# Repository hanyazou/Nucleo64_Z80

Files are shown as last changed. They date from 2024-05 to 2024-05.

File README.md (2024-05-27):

# Nucleo64 Z80

Nucleo64 Z80 is a Z80 expansion board for the STM32 Nucleo 64 board.
It adds a Z80 CPU and SRAM to the Nucleo.
The Z80's I/O access is handled by the STM32 MCU on the Nucleo.

## Features

- Simple 2-chip configuration with Z80 and SRAM, no additional logic IC needed
- Board test firmware includes Microsoft BASIC
- Faster Z80 CPU execution (clock up to 20MHz)
- I2C and SPI devices can be used with the Z80 (custom firmware required)

The Nucleo64 Z80 is derived from satoshiokue's MEZ80RAM and SuperMEZ80-CPM.

## Appearance

The white boards in the following pictures are the Nucleo64 Z80.

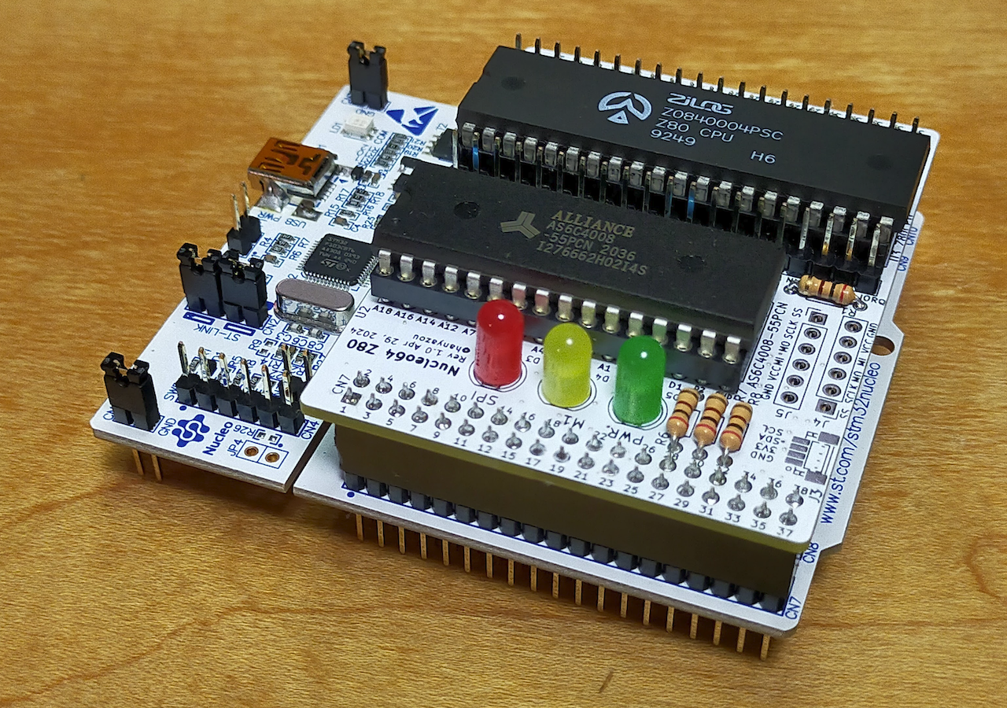
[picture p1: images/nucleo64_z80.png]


## Block Diagram

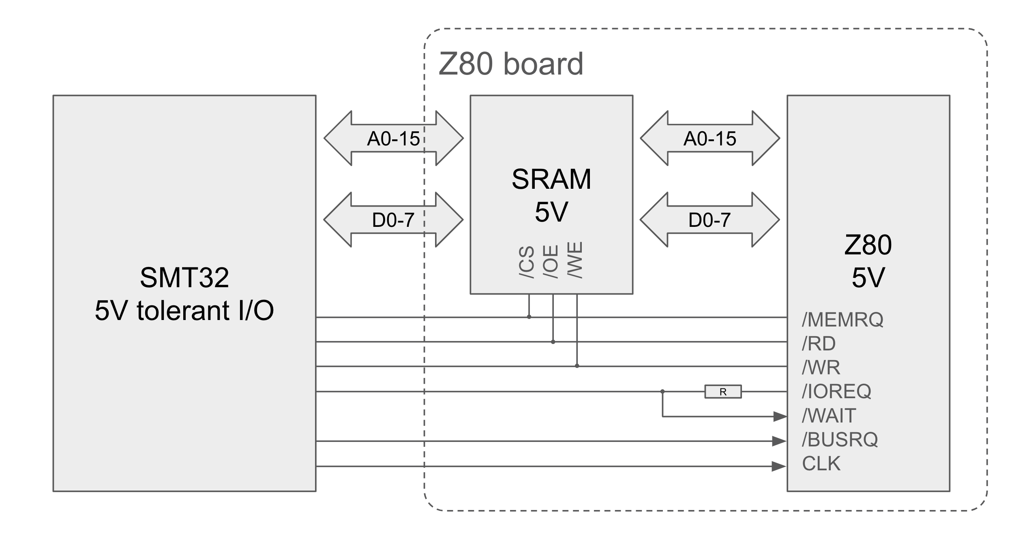
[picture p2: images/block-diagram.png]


## Required Components

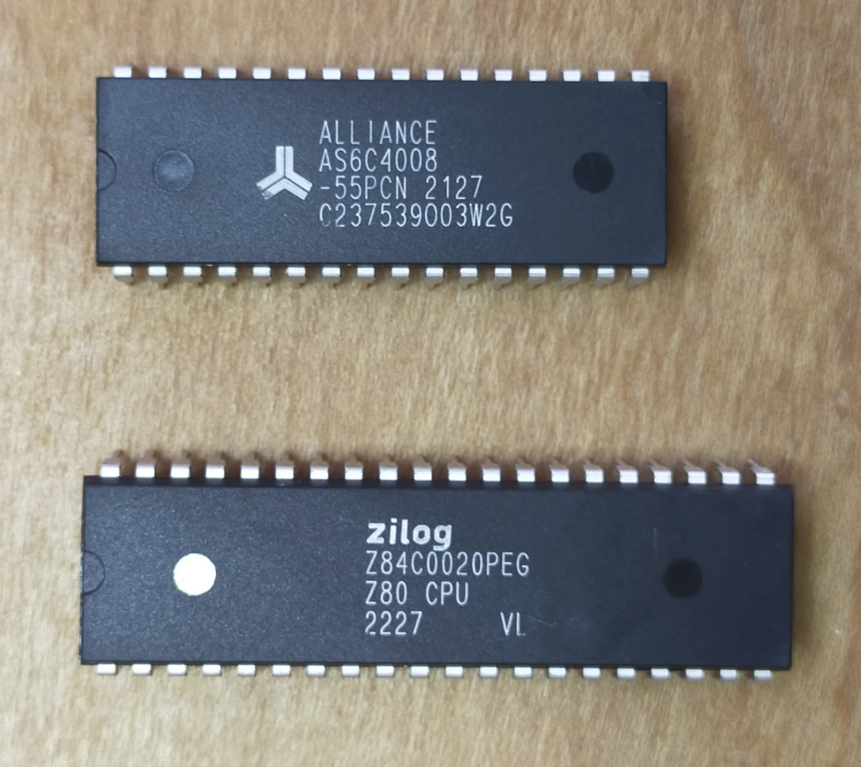
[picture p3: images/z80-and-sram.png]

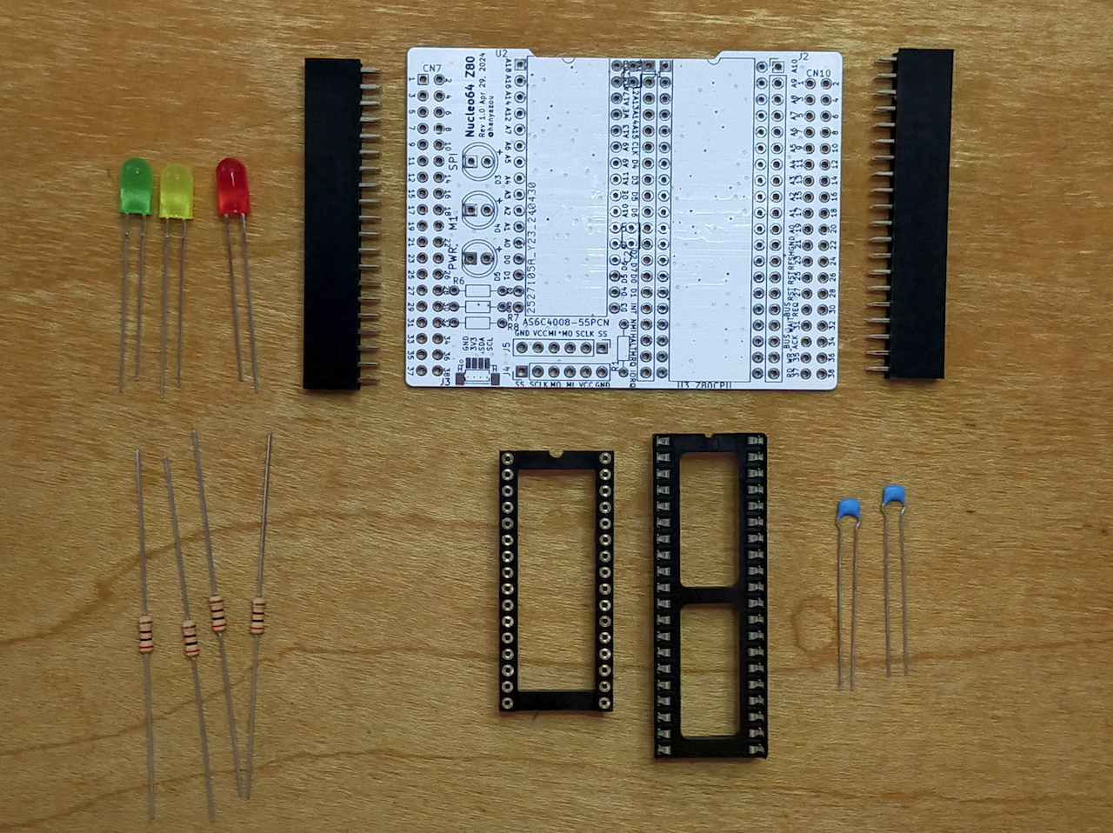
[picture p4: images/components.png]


### ICs

- U3 Z80 (DIP 40 pin) *1
- U2 AS6C4008-55 SRAM 4Mbit (DIP 32 pin) *2

### Through-hole Components

- U3 IC socket (DIP 40 pin)
- U2 IC socket (DIP 32 pin)
- C1, C2 Capacitors 0.1uF
- R1 Resistor 200 ohms
- J4, J5 Pin headers (0.1" pitch 19x2 pin)
- D3, D4, D5 LEDs
- R6, R7, R8 Resistors 100 ohms 1/4W (resistor value may vary depending on the LED)

### Optional Components

- J3 SH 1.0 JST 4 pin connector *3
- J4, J5 Pin sockets (0.1" pitch 6x1 pin) *4

*1) Z80C0004 (4MHz) or higher recommended  
*2) 512Kbit (64KB) might be sufficient  
*3) For I2C Qwiic devices  
*4) For the micro SD card slot, use the one for ARM Arduino as shown on the following page:  
https://www.amazon.com/dp/B0B7WZQVHS

## Build Instructions

With fewer components, assembly is straightforward.
Solder all components except the 19x2 pin headers first, then solder the pin headers last.

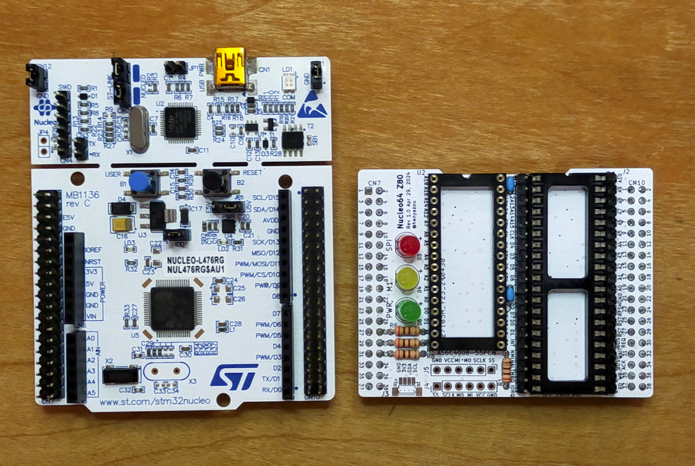
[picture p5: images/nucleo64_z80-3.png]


## Board Test Firmware

The `FW/board_test` folder contains a test firmware project for STM32 CubeIDE.
The current target is STM32 Nucleo-64 STM32L476RG.

This firmware includes Microsoft BASIC.
When the Z80 runs at 20 MHz, executing ASCIIARTM.BAS takes 61 seconds.

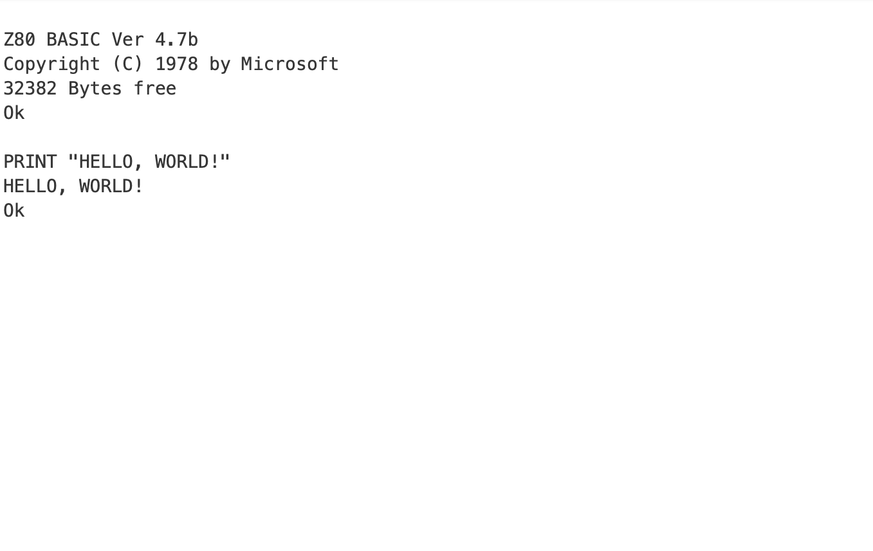
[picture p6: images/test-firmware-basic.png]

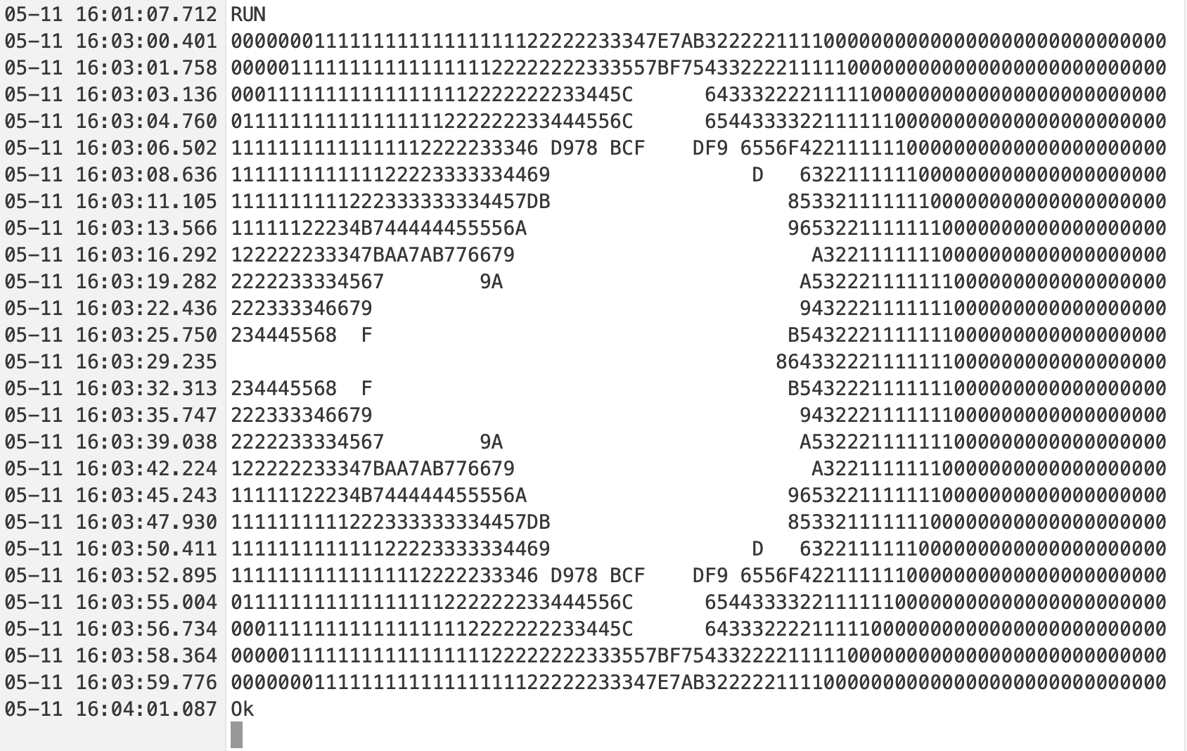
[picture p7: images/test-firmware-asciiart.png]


The Z80 clock is generated by TIM5 in the STM32 L476RG.
The prescaler of TIM5 is set to 10 - 1, so the Z80 runs at 4 MHz, which is 1/20 of the system clock (80 MHz).
If you change the prescaler to 1, the clock will be 20 MHz.

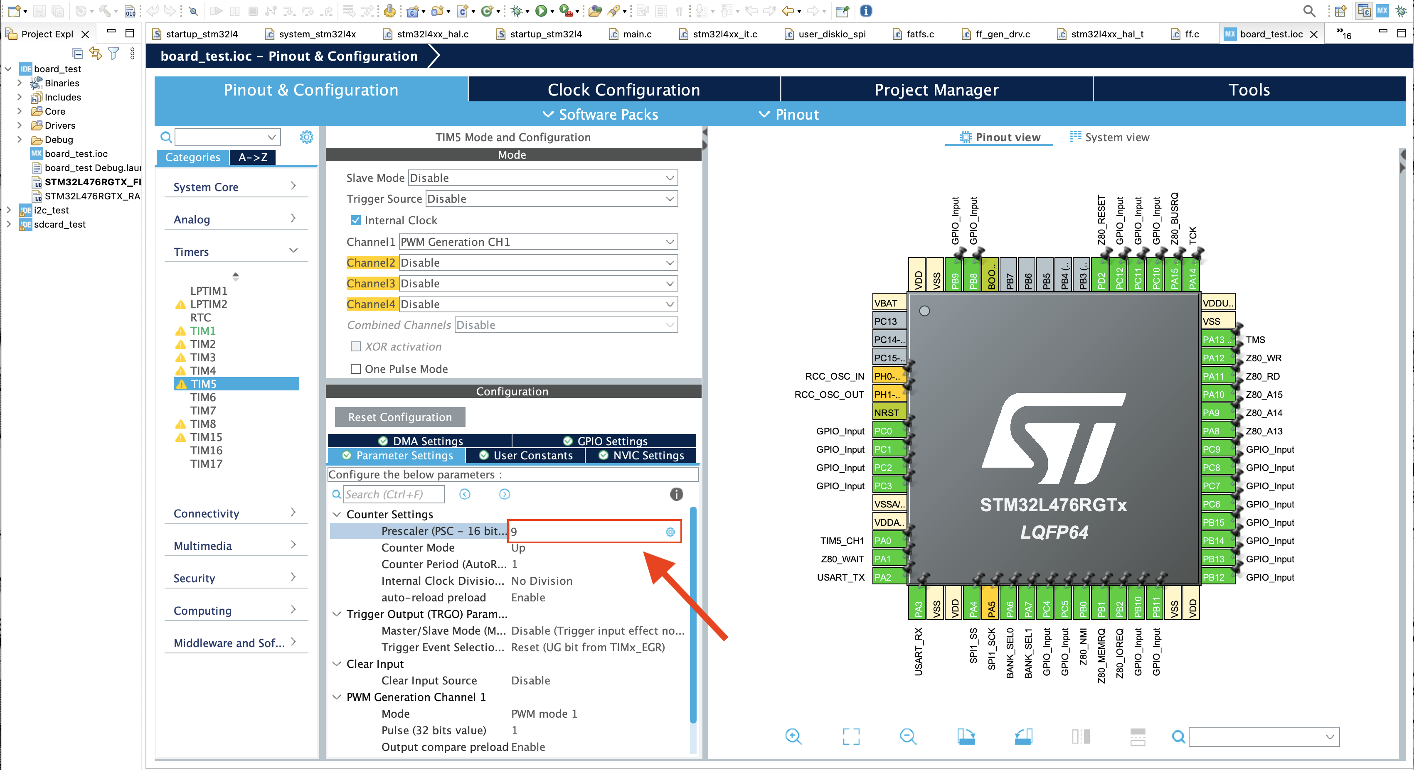
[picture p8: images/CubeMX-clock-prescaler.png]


## References

### SuperMEZ80-CPM

https://github.com/hanyazou/SuperMEZ80-CPM

### EMUZ80

https://vintagechips.wordpress.com/2022/03/05/emuz80_reference/

### MEZ80RAM

https://github.com/satoshiokue/MEZ80RAM

### NUCLEO-L476RG

https://www.st.com/en/evaluation-tools/nucleo-l476rg.html

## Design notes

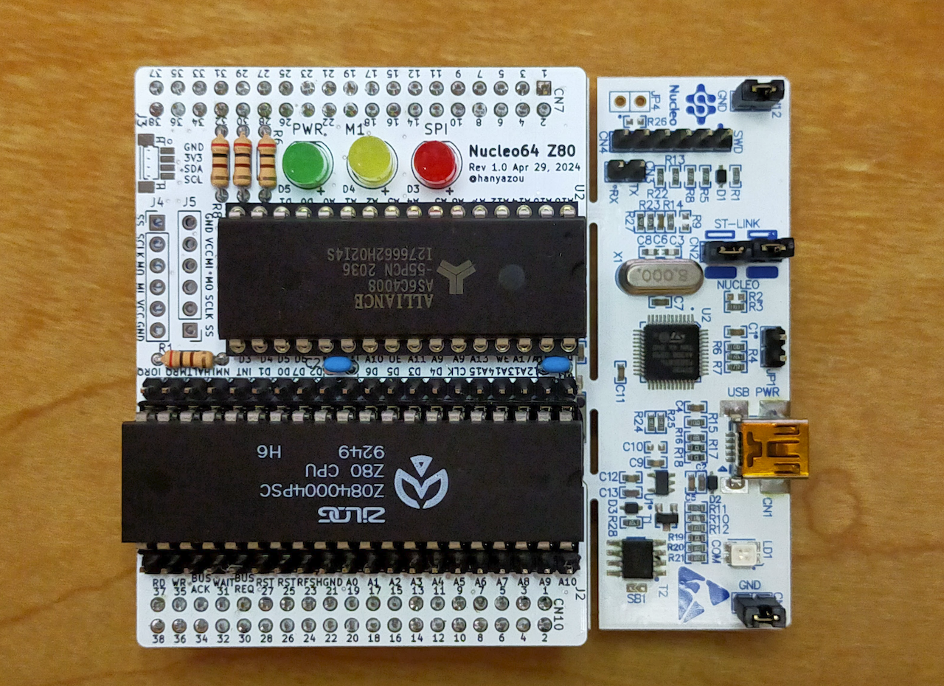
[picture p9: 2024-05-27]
images/nucleo64_z80-2.png

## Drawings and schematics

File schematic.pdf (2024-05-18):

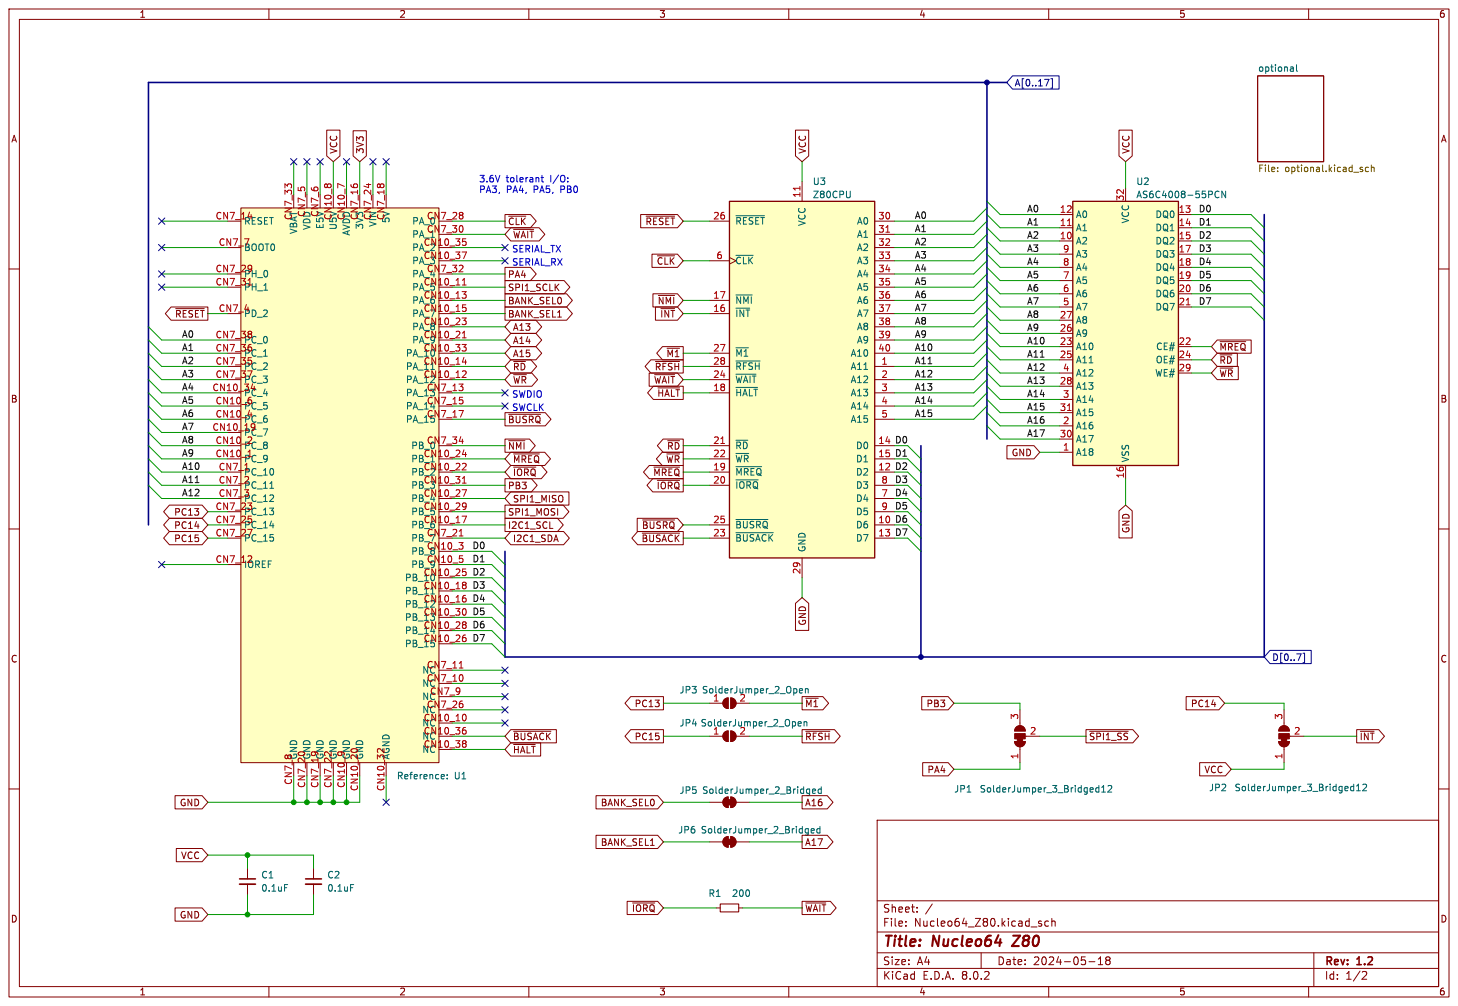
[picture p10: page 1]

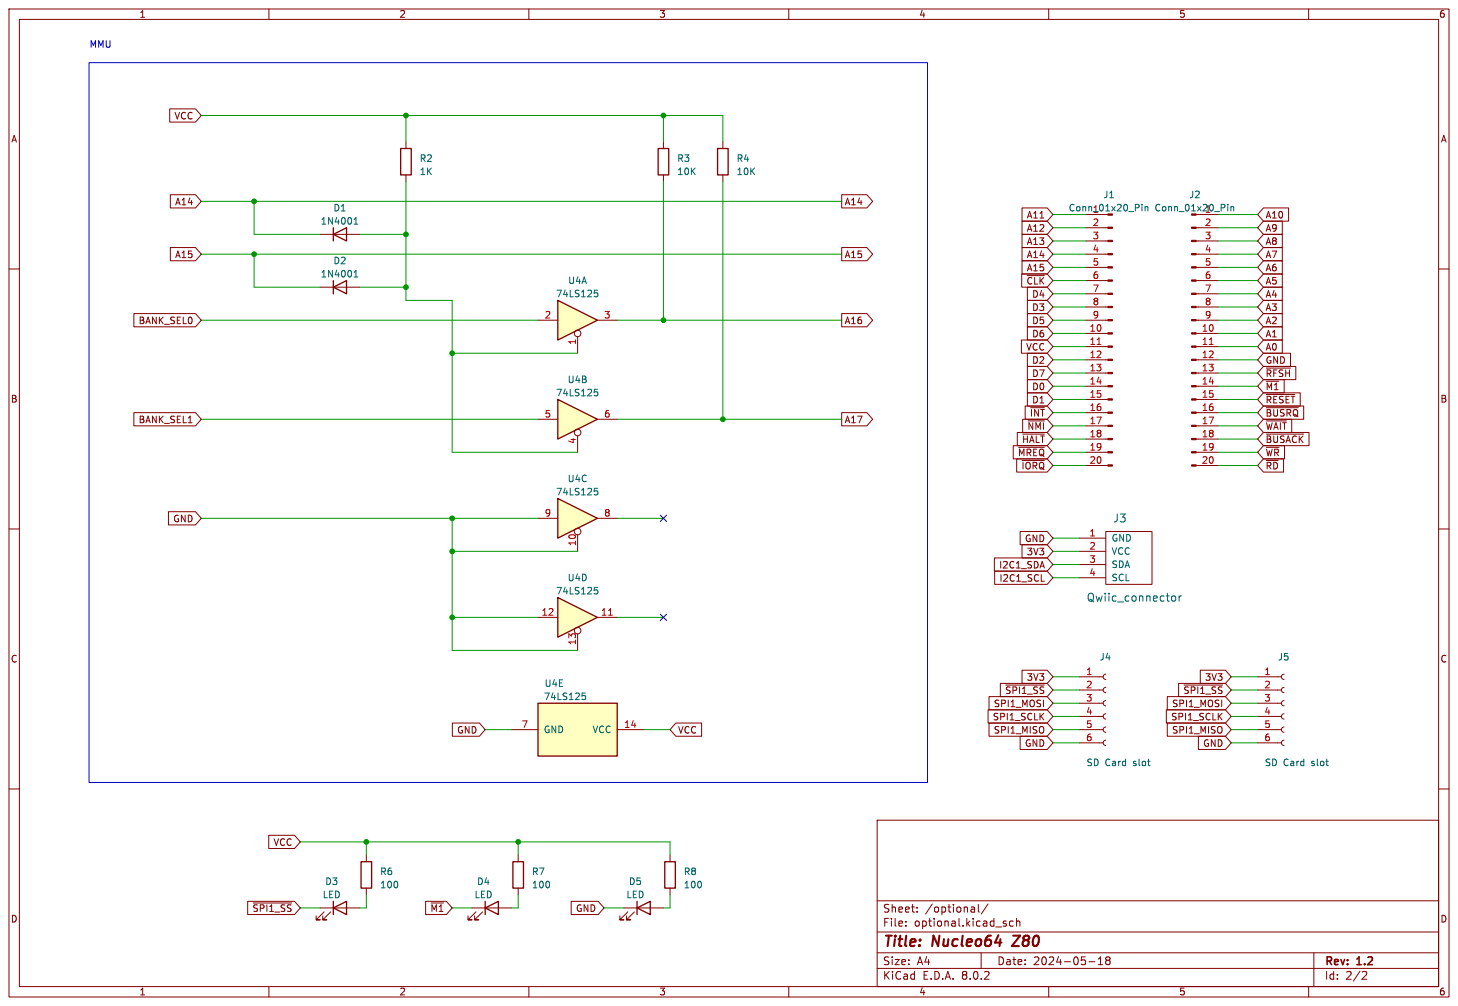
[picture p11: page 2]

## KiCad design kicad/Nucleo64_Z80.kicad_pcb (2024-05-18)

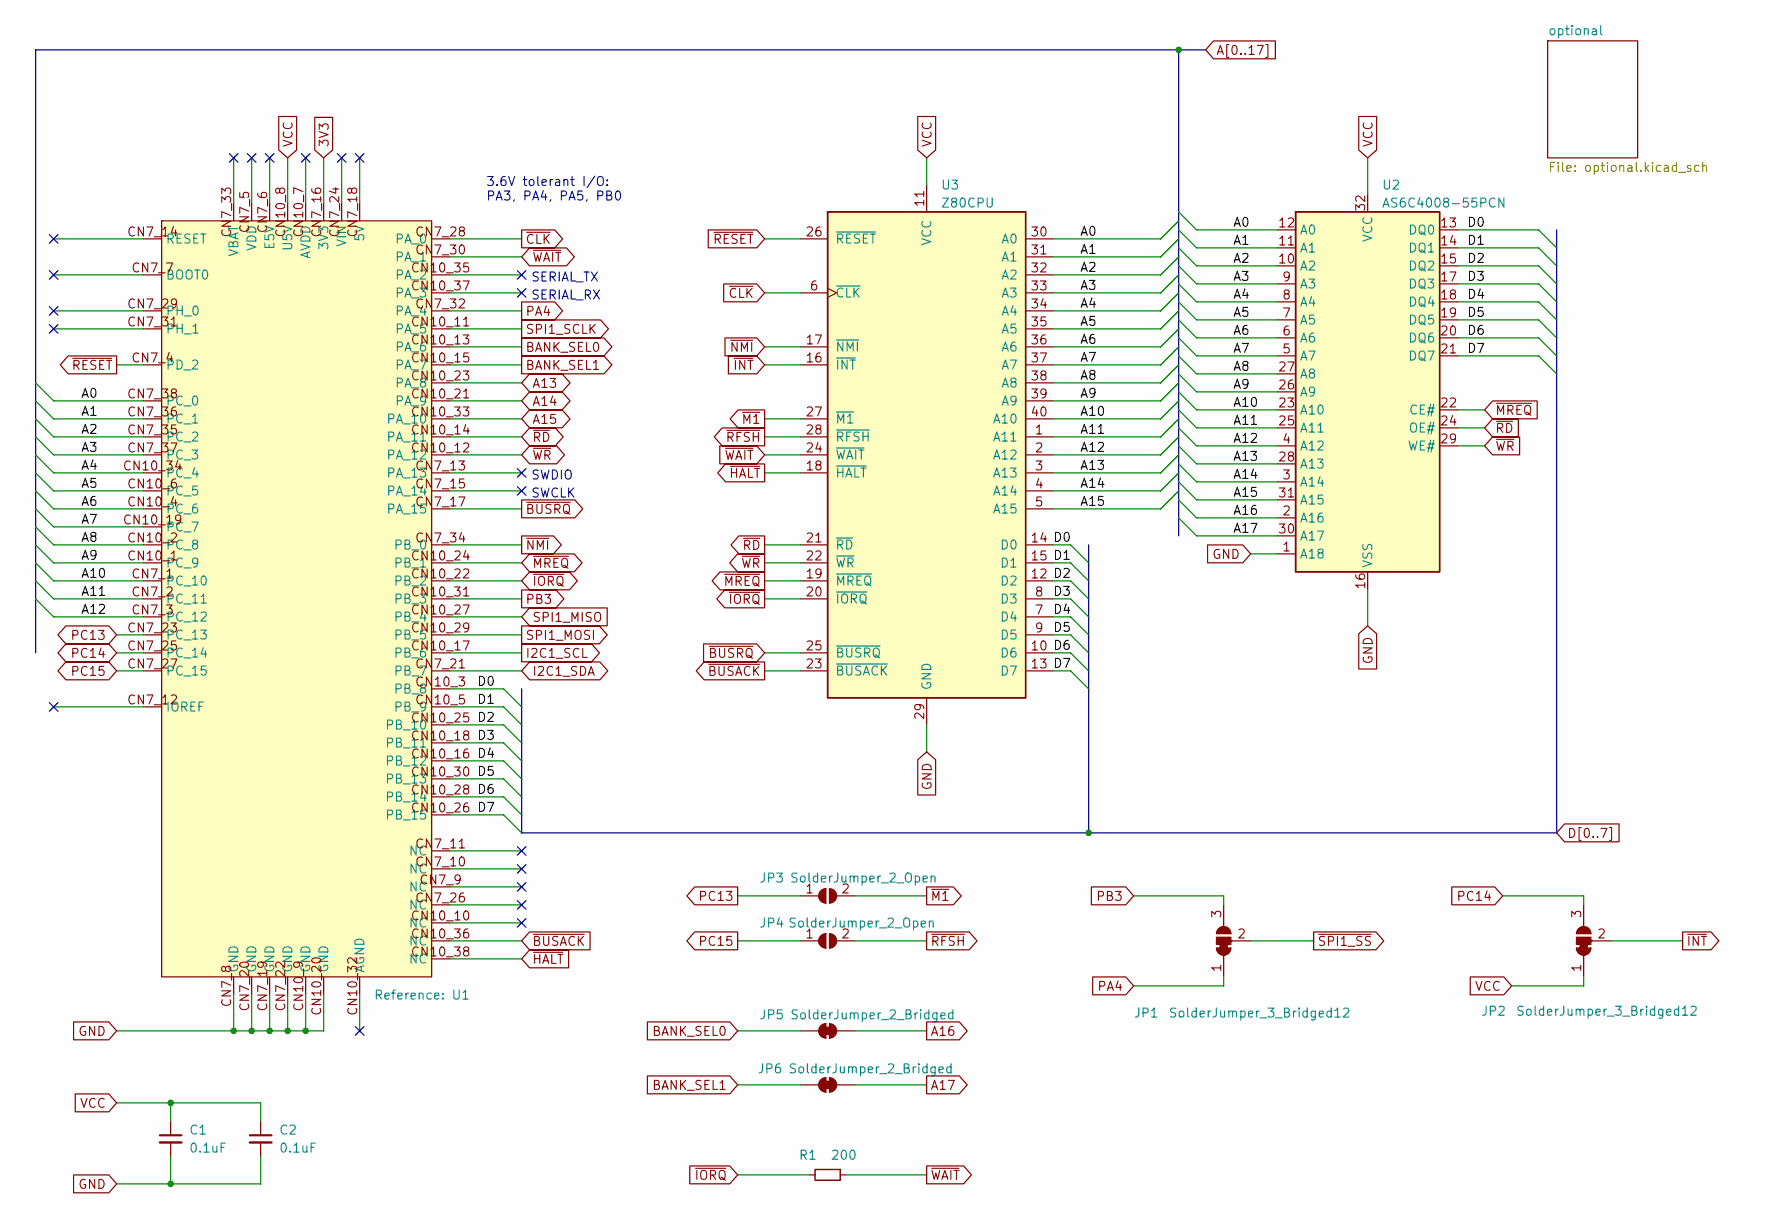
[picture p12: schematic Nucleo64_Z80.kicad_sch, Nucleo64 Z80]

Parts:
C1, C2: 0.1uF; C_Disc_D3.8mm_W2.6mm_P2.50mm
JP1, JP2: SolderJumper_3_Bridged12; SolderJumper-3_P1.3mm_Bridged12_RoundedPad1.0x1.5mm_NumberL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
JP3, JP4: SolderJumper_2_Open; SolderJumper-2_P1.3mm_Open_RoundedPad1.0x1.5mm
JP5, JP6: SolderJumper_2_Bridged; SolderJumper-2_P1.3mm_Bridged_RoundedPad1.0x1.5mm
R1: 200; R_Axial_DIN0204_L3.6mm_D1.6mm_P7.62mm_Horizontal
U1: NUCLEO64_morpho
U2: AS6C4008-55PCN; DIP-32_W15.24mm
U3: Z80CPU; DIP-40_W15.24mm

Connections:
3V3: U1.CN7_16 (3V3); also elsewhere on the board
A0: U1.CN7_38 (PC_0), U2.12 (A0), U3.30 (A0); also elsewhere on the board
A1: U1.CN7_36 (PC_1), U2.11 (A1), U3.31 (A1); also elsewhere on the board
A2: U1.CN7_35 (PC_2), U2.10 (A2), U3.32 (A2); also elsewhere on the board
A3: U1.CN7_37 (PC_3), U2.9 (A3), U3.33 (A3); also elsewhere on the board
A4: U1.CN10_34 (PC_4), U2.8 (A4), U3.34 (A4); also elsewhere on the board
A5: U1.CN10_6 (PC_5), U2.7 (A5), U3.35 (A5); also elsewhere on the board
A6: U1.CN10_4 (PC_6), U2.6 (A6), U3.36 (A6); also elsewhere on the board
A7: U1.CN10_19 (PC_7), U2.5 (A7), U3.37 (A7); also elsewhere on the board
A8: U1.CN10_2 (PC_8), U2.27 (A8), U3.38 (A8); also elsewhere on the board
A9: U1.CN10_1 (PC_9), U2.26 (A9), U3.39 (A9); also elsewhere on the board
A10: U1.CN7_1 (PC_10), U2.23 (A10), U3.40 (A10); also elsewhere on the board
A11: U1.CN7_2 (PC_11), U2.25 (A11), U3.1 (A11); also elsewhere on the board
A12: U1.CN7_3 (PC_12), U2.4 (A12), U3.2 (A12); also elsewhere on the board
A13: U1.CN10_23 (PA_8), U2.28 (A13), U3.3 (A13); also elsewhere on the board
A14: U1.CN10_21 (PA_9), U2.3 (A14), U3.4 (A14); also elsewhere on the board
A15: U1.CN10_33 (PA_10), U2.31 (A15), U3.5 (A15); also elsewhere on the board
A16: JP5.2 (B), U2.2 (A16); also elsewhere on the board
A17: JP6.2 (B), U2.30 (A17); also elsewhere on the board
BANK_SEL0: JP5.1 (A), U1.CN10_13 (PA_6); also elsewhere on the board
BANK_SEL1: JP6.1 (A), U1.CN10_15 (PA_7); also elsewhere on the board
D0: U1.CN10_3 (PB_8), U2.13 (DQ0), U3.14 (D0); also elsewhere on the board
D1: U1.CN10_5 (PB_9), U2.14 (DQ1), U3.15 (D1); also elsewhere on the board
D2: U1.CN10_25 (PB_10), U2.15 (DQ2), U3.12 (D2); also elsewhere on the board
D3: U1.CN10_18 (PB_11), U2.17 (DQ3), U3.8 (D3); also elsewhere on the board
D4: U1.CN10_16 (PB_12), U2.18 (DQ4), U3.7 (D4); also elsewhere on the board
D5: U1.CN10_30 (PB_13), U2.19 (DQ5), U3.9 (D5); also elsewhere on the board
D6: U1.CN10_28 (PB_14), U2.20 (DQ6), U3.10 (D6); also elsewhere on the board
D7: U1.CN10_26 (PB_15), U2.21 (DQ7), U3.13 (D7); also elsewhere on the board
GND: C1.2, C2.2, U1.CN7_8 (GND), U1.CN7_19 (GND), U1.CN7_20 (GND), U1.CN7_22 (GND), U1.CN10_9 (GND), U1.CN10_20 (GND), U2.1 (A18), U2.16 (VSS), U3.29 (GND); also elsewhere on the board
I2C1_SCL: U1.CN10_17 (PB_6); also elsewhere on the board
I2C1_SDA: U1.CN7_21 (PB_7); also elsewhere on the board
PA4: JP1.1 (A), U1.CN7_32 (PA_4)
PB3: JP1.3 (B), U1.CN10_31 (PB_3)
PC13: JP3.1 (A), U1.CN7_23 (PC_13)
PC14: JP2.3 (B), U1.CN7_25 (PC_14)
PC15: JP4.1 (A), U1.CN7_27 (PC_15)
SPI1_MISO: U1.CN10_27 (PB_4); also elsewhere on the board
SPI1_MOSI: U1.CN10_29 (PB_5); also elsewhere on the board
SPI1_SCLK: U1.CN10_11 (PA_5); also elsewhere on the board
VCC: C1.1, C2.1, JP2.1 (A), U1.CN10_8 (U5V), U2.32 (VCC), U3.11 (VCC); also elsewhere on the board
~BUSACK: U1.CN10_36 (NC), U3.23 (~BUSACK); also elsewhere on the board
~BUSRQ: U1.CN7_17 (PA_15), U3.25 (~BUSRQ); also elsewhere on the board
~CLK: U1.CN7_28 (PA_0), U3.6 (~CLK); also elsewhere on the board
~HALT: U1.CN10_38 (NC), U3.18 (~HALT); also elsewhere on the board
~INT: JP2.2 (C), U3.16 (~INT); also elsewhere on the board
~IORQ: R1.2, U1.CN10_22 (PB_2), U3.20 (~IORQ); also elsewhere on the board
~M1: JP3.2 (B), U3.27 (~M1); also elsewhere on the board
~MREQ: U1.CN10_24 (PB_1), U2.22 (CE#), U3.19 (~MREQ); also elsewhere on the board
~NMI: U1.CN7_34 (PB_0), U3.17 (~NMI); also elsewhere on the board
~RD: U1.CN10_14 (PA_11), U2.24 (OE#), U3.21 (~RD); also elsewhere on the board
~RESET: U1.CN7_4 (PD_2), U3.26 (~RESET); also elsewhere on the board
~RFSH: JP4.2 (B), U3.28 (~RFSH); also elsewhere on the board
~SPI1_SS: JP1.2 (C); also elsewhere on the board
~WAIT: R1.1, U1.CN7_30 (PA_1), U3.24 (~WAIT); also elsewhere on the board
~WR: U1.CN10_12 (PA_12), U2.29 (WE#), U3.22 (~WR); also elsewhere on the board

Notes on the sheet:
SWDIO
SERIAL_RX
SERIAL_TX
SWCLK
3.6V tolerant I/O: PA3, PA4, PA5, PB0

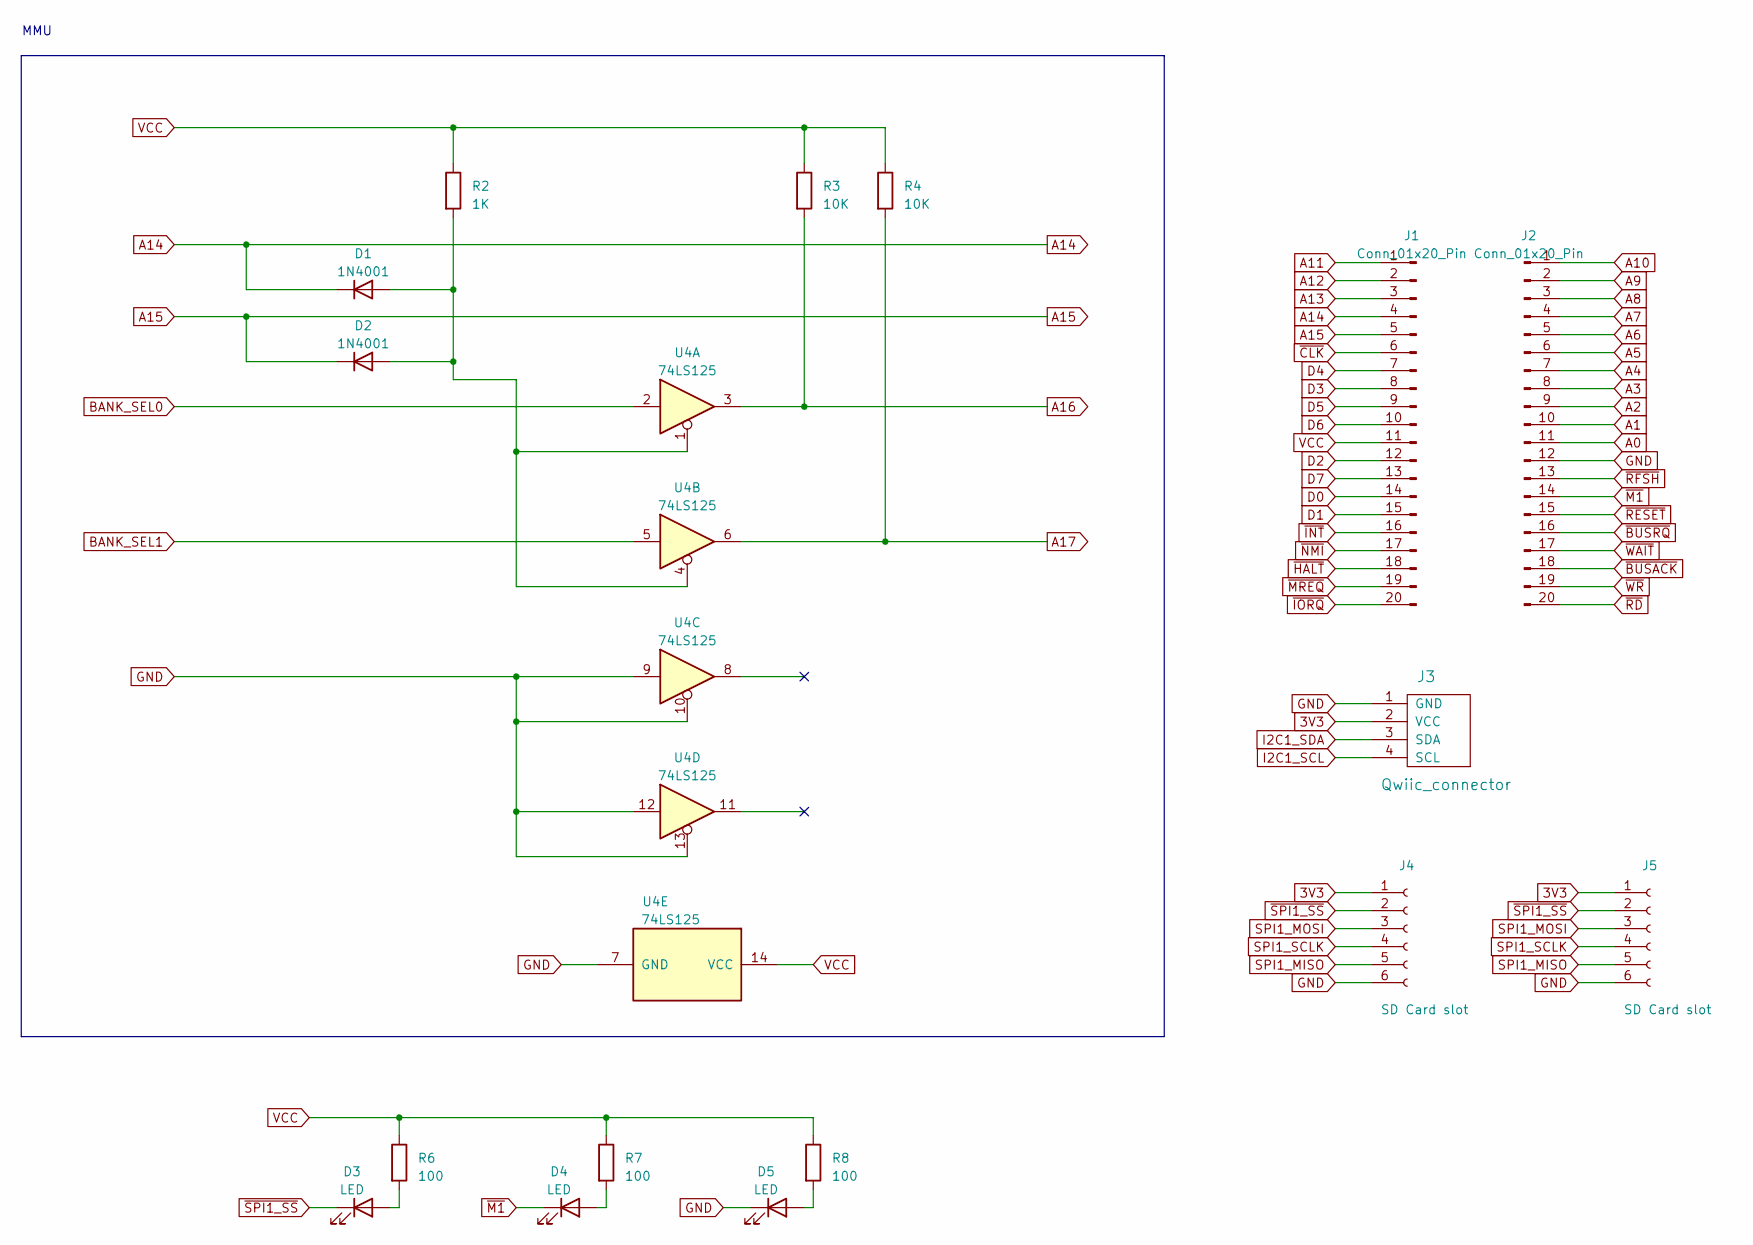
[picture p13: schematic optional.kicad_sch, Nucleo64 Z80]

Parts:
D1, D2: 1N4001; D_0805_2012Metric_Pad1.15x1.40mm_HandSolder
D3, D4, D5: LED; LED_D5.0mm
J1, J2: Conn_01x20_Pin; PinHeader_1x20_P2.54mm_Vertical
J3: Qwiic_connector; Qwiic_I2C_1.00mm_4pin
J4, J5: SD Card slot; PinHeader_1x06_P2.54mm_Vertical
R2: 1K; R_0805_2012Metric_Pad1.20x1.40mm_HandSolder
R3, R4: 10K; R_0805_2012Metric_Pad1.20x1.40mm_HandSolder
R6, R7, R8: 100; R_Axial_DIN0204_L3.6mm_D1.6mm_P7.62mm_Horizontal
U4: 74LS125; SSOP-14_5.3x6.2mm_P0.65mm

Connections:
3V3: J3.2 (VCC), J4.1, J5.1; also elsewhere on the board
A0: J2.11; also elsewhere on the board
A1: J2.10; also elsewhere on the board
A2: J2.9; also elsewhere on the board
A3: J2.8; also elsewhere on the board
A4: J2.7; also elsewhere on the board
A5: J2.6; also elsewhere on the board
A6: J2.5; also elsewhere on the board
A7: J2.4; also elsewhere on the board
A8: J2.3; also elsewhere on the board
A9: J2.2; also elsewhere on the board
A10: J2.1; also elsewhere on the board
A11: J1.1; also elsewhere on the board
A12: J1.2; also elsewhere on the board
A13: J1.3; also elsewhere on the board
A14: D1.1 (K), J1.4; also elsewhere on the board
A15: D2.1 (K), J1.5; also elsewhere on the board
A16: R3.2, U4.3; also elsewhere on the board
A17: R4.2, U4.6; also elsewhere on the board
BANK_SEL0: U4.2; also elsewhere on the board
BANK_SEL1: U4.5; also elsewhere on the board
D0: J1.14; also elsewhere on the board
D1: J1.15; also elsewhere on the board
D2: J1.12; also elsewhere on the board
D3: J1.8; also elsewhere on the board
D4: J1.7; also elsewhere on the board
D5: J1.9; also elsewhere on the board
D6: J1.10; also elsewhere on the board
D7: J1.13; also elsewhere on the board
GND: D5.1 (K), J2.12, J3.1 (GND), J4.6, J5.6, U4.7 (GND), U4.9, U4.10, U4.12, U4.13; also elsewhere on the board
I2C1_SCL: J3.4 (SCL); also elsewhere on the board
I2C1_SDA: J3.3 (SDA); also elsewhere on the board
unnamed: D1.2 (A), D2.2 (A), R2.2, U4.1, U4.4
unnamed: D3.2 (A), R6.2
unnamed: D4.2 (A), R7.2
unnamed: D5.2 (A), R8.2
SPI1_MISO: J4.5, J5.5; also elsewhere on the board
SPI1_MOSI: J4.3, J5.3; also elsewhere on the board
SPI1_SCLK: J4.4, J5.4; also elsewhere on the board
VCC: J1.11, R2.1, R3.1, R4.1, R6.1, R7.1, R8.1, U4.14 (VCC); also elsewhere on the board
~BUSACK: J2.18; also elsewhere on the board
~BUSRQ: J2.16; also elsewhere on the board
~CLK: J1.6; also elsewhere on the board
~HALT: J1.18; also elsewhere on the board
~INT: J1.16; also elsewhere on the board
~IORQ: J1.20; also elsewhere on the board
~M1: D4.1 (K), J2.14; also elsewhere on the board
~MREQ: J1.19; also elsewhere on the board
~NMI: J1.17; also elsewhere on the board
~RD: J2.20; also elsewhere on the board
~RESET: J2.15; also elsewhere on the board
~RFSH: J2.13; also elsewhere on the board
~SPI1_SS: D3.1 (K), J4.2, J5.2; also elsewhere on the board
~WAIT: J2.17; also elsewhere on the board
~WR: J2.19; also elsewhere on the board

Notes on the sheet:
MMU

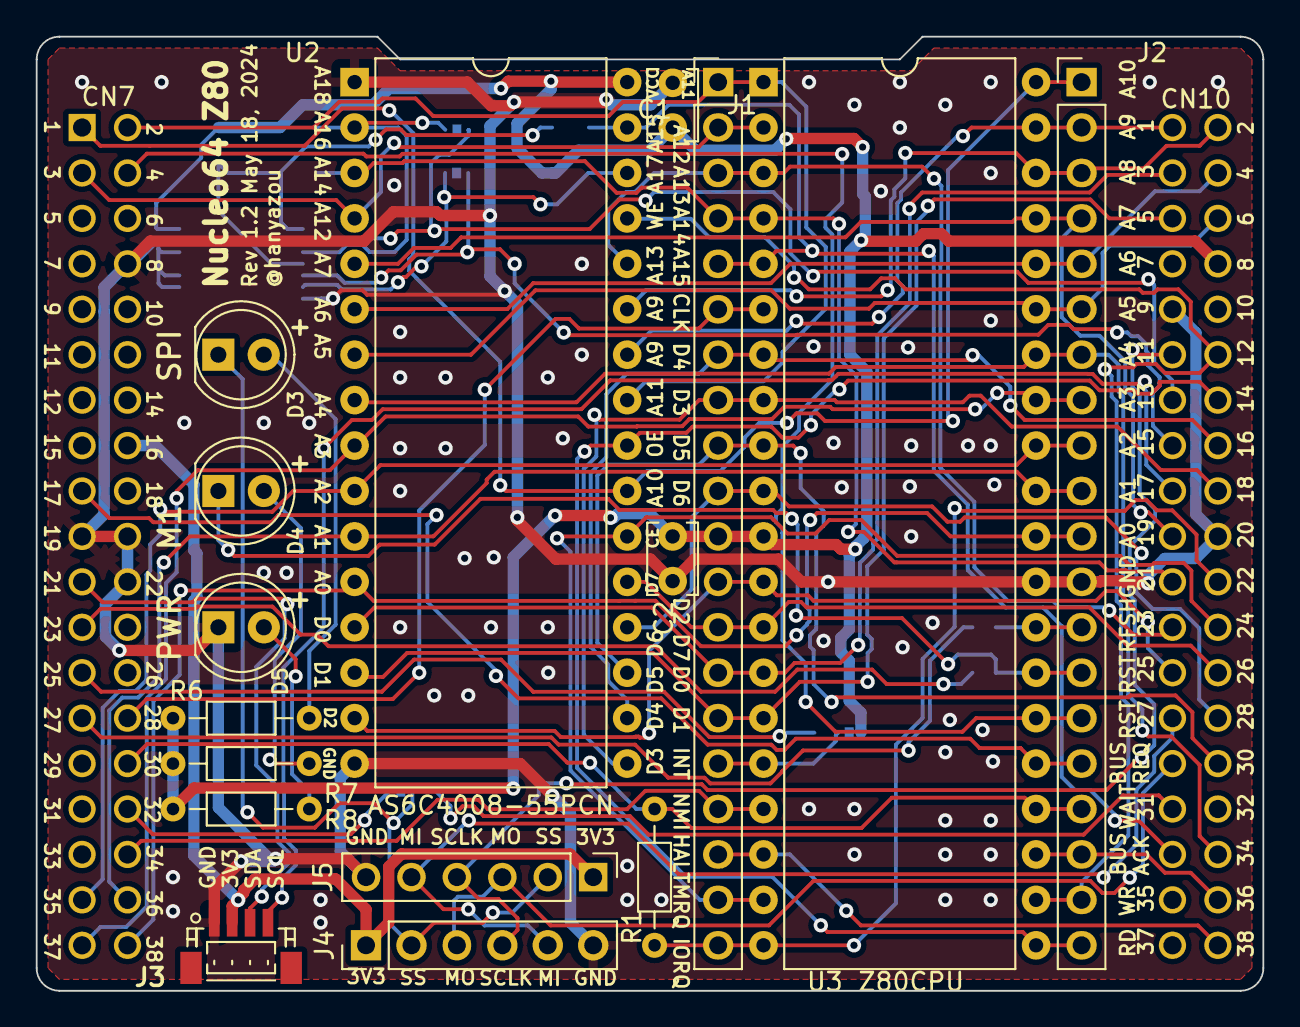
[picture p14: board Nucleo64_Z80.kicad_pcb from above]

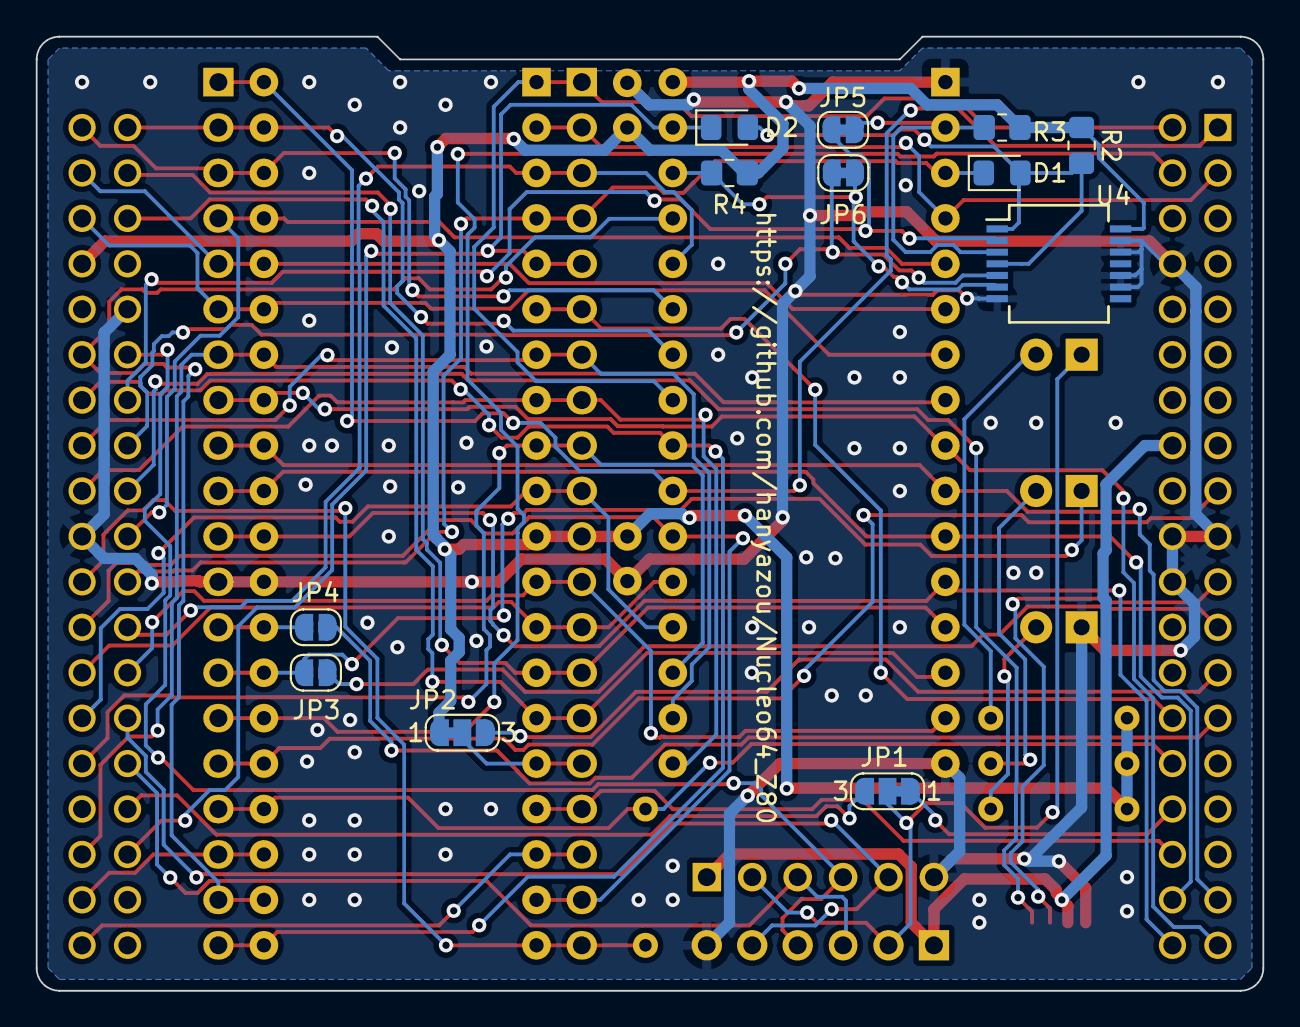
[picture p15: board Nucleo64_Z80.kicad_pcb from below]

Board: 2 copper layers, 68.6 x 53.3 mm, 29 parts (12 on the bottom side), 60 nets.

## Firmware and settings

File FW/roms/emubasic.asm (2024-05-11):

;	EMUBASIC based on GRANT's BASIC
;	TARGET: EMUZ80
;	ASSEMBLER: ARCPIT XZ80.EXE
;
;	START UP ROUTINE
;	VERSION 1.0, 2022/02/15
;	WRITTEN by TETSUYA SUZUKI
;
;	MEMORY ASIGN
ROMTOP	EQU	0000H
RAMTOP	EQU	8000H
RAMSIZ	EQU	1000H
TSTACK	EQU	80EDH
;
;	UART REGISTER ADDRESS
UARTDR	EQU	00H	; UART DATA REGISTOR
UARTCR	EQU	01H	; UART CONTROL REGISTOR
;
;	RESET (RST 00H)
	ORG	ROMTOP
	DI
	LD	SP,TSTACK
	JP	SINIT
;
;	PUT 1CHAR (RST 08H)
	ORG	ROMTOP+08H
	JP	TXA
;
;	GET 1CHAR (RST 10H)
	ORG	ROMTOP+10H
	JP	RXA
;
;	KBHIT (RST 18H)
	ORG	ROMTOP+18H
	JP	KBHIT
;
;	UART -> A
RXA:	IN	A,(UARTCR)
	BIT	0,A
	JR	Z,RXA
	IN	A,(UARTDR)
	CP	'a'
	RET	C
	CP	'z'+1
	RET	NC
	AND	0DFH
	RET
;
;	CHECK RECEIVE STATUS
KBHIT:	IN	A,(UARTCR)
	BIT	0,A
	RET
;
;	A -> UART
TXA:	PUSH	AF
TXAST1:	IN	A,(UARTCR)
	BIT	1,A
	JR	Z,TXAST1
	POP	AF
	OUT	(UARTDR),A
	RET
;
;
;	SYSTEM INITIALIZE
SINIT:
	JP	COLD
;
;==================================================================================
; The updates to the original BASIC within this file are copyright Grant Searle
;
; You have permission to use this for NON COMMERCIAL USE ONLY
; If you wish to use it elsewhere, please include an acknowledgement to myself.
;
; http://searle.hostei.com/grant/index.html
;
; eMail: home.micros01@btinternet.com
;
; If the above don't work, please perform an Internet search to see if I have
; updated the web page hosting service.
;
;==================================================================================
;
; NASCOM ROM BASIC Ver 4.7, (C) 1978 Microsoft
; Scanned from source published in 80-BUS NEWS from Vol 2, Issue 3
; (May-June 1983) to Vol 3, Issue 3 (May-June 1984)
; Adapted for the freeware Zilog Macro Assembler 2.10 to produce
; the original ROM code (checksum A934H). PA
;
; GENERAL EQUATES
;
CTRLC	EQU	03H		; Control "C"
CTRLG	EQU	07H		; Control "G"
BKSP	EQU	08H		; Back space
LF	EQU	0AH		; Line feed
CS	EQU	0CH		; Clear screen
CR	EQU	0DH		; Carriage return
CTRLO	EQU	0FH		; Control "O"
CTRLQ	EQU	11H		; Control "Q"
CTRLR	EQU	12H		; Control "R"
CTRLS	EQU	13H		; Control "S"
CTRLU	EQU	15H		; Control "U"
ESC	EQU	1BH		; Escape
DEL	EQU	7FH		; Delete
;
; BASIC WORK SPACE LOCATIONS
;
WRKSPC	EQU	8045H		; BASIC Work space
USR	EQU	WRKSPC+3H	; "USR (x)" jump
OUTSUB	EQU	WRKSPC+6H	; "OUT p,n"
OTPORT	EQU	WRKSPC+7H	; Port (p)
DIVSUP	EQU	WRKSPC+9H	; Division support routine
DIV1	EQU	WRKSPC+0AH	; <- Values
DIV2	EQU	WRKSPC+0EH	; <- to
DIV3	EQU	WRKSPC+12H	; <- be
DIV4	EQU	WRKSPC+15H	; <- inserted
SEED	EQU	WRKSPC+17H	; Random number seed
LSTRND	EQU	WRKSPC+3AH	; Last random number
INPSUB	EQU	WRKSPC+3EH	; #INP (x)" Routine
INPORT	EQU	WRKSPC+3FH	; PORT (x)
NULLS	EQU	WRKSPC+41H	; Number of nulls
LWIDTH	EQU	WRKSPC+42H	; Terminal width
COMMAN	EQU	WRKSPC+43H	; Width for commas
NULFLG	EQU	WRKSPC+44H	; Null after input byte flag
CTLOFG	EQU	WRKSPC+45H	; Control "O" flag
LINESC	EQU	WRKSPC+46H	; Lines counter
LINESN	EQU	WRKSPC+48H	; Lines number
CHKSUM	EQU	WRKSPC+4AH	; Array load/save check sum
NMIFLG	EQU	WRKSPC+4CH	; Flag for NMI break routine
BRKFLG	EQU	WRKSPC+4DH	; Break flag
RINPUT	EQU	WRKSPC+4EH	; Input reflection
POINT	EQU	WRKSPC+51H	; "POINT" reflection (unused)
PSET	EQU	WRKSPC+54H	; "SET"	reflection
RESET	EQU	WRKSPC+57H	; "RESET" reflection
STRSPC	EQU	WRKSPC+5AH	; Bottom of string space
LINEAT	EQU	WRKSPC+5CH	; Current line number
BASTXT	EQU	WRKSPC+5EH	; Pointer to start of program
BUFFER	EQU	WRKSPC+61H	; Input buffer
STACK	EQU	WRKSPC+66H	; Initial stack
CURPOS	EQU	WRKSPC+0ABH	; Character position on line
LCRFLG	EQU	WRKSPC+0ACH	; Locate/Create flag
TYPE	EQU	WRKSPC+0ADH	; Data type flag
DATFLG	EQU	WRKSPC+0AEH	; Literal statement flag
LSTRAM	EQU	WRKSPC+0AFH	; Last available RAM
TMSTPT	EQU	WRKSPC+0B1H	; Temporary string pointer
TMSTPL	EQU	WRKSPC+0B3H	; Temporary string pool
TMPSTR	EQU	WRKSPC+0BFH	; Temporary string
STRBOT	EQU	WRKSPC+0C3H	; Bottom of string space
CUROPR	EQU	WRKSPC+0C5H	; Current operator in EVAL
LOOPST	EQU	WRKSPC+0C7H	; First statement of loop
DATLIN	EQU	WRKSPC+0C9H	; Line of current DATA item
FORFLG	EQU	WRKSPC+0CBH	; "FOR" loop flag
LSTBIN	EQU	WRKSPC+0CCH	; Last byte entered
READFG	EQU	WRKSPC+0CDH	; Read/Input flag
BRKLIN	EQU	WRKSPC+0CEH	; Line of break
NXTOPR	EQU	WRKSPC+0D0H	; Next operator in EVAL
ERRLIN	EQU	WRKSPC+0D2H	; Line of error
CONTAD	EQU	WRKSPC+0D4H	; Where to CONTinue
PROGND	EQU	WRKSPC+0D6H	; End of program
VAREND	EQU	WRKSPC+0D8H	; End of variables
ARREND	EQU	WRKSPC+0DAH	; End of arrays
NXTDAT	EQU	WRKSPC+0DCH	; Next data item
FNRGNM	EQU	WRKSPC+0DEH	; Name of FN argument
FNARG	EQU	WRKSPC+0E0H	; FN argument value
FPREG	EQU	WRKSPC+0E4H	; Floating point register
FPEXP	EQU	FPREG+3		; Floating point exponent
SGNRES	EQU	WRKSPC+0E8H	; Sign of result
PBUFF	EQU	WRKSPC+0E9H	; Number print buffer
MULVAL	EQU	WRKSPC+0F6H	; Multiplier
PROGST	EQU	WRKSPC+0F9H	; Start of program text area
STLOOK	EQU	WRKSPC+15DH	; Start of memory test
;
; BASIC ERROR CODE VALUES
;
NF	EQU	00H		; NEXT without FOR
SN	EQU	02H		; Syntax error
RG	EQU	04H		; RETURN without GOSUB
OD	EQU	06H		; Out of DATA
FC	EQU	08H		; Function call error
OV	EQU	0AH		; Overflow
OM	EQU	0CH		; Out of memory
UL	EQU	0EH		; Undefined line number
BS	EQU	10H		; Bad subscript
RD	EQU	12H		; Re-DIMensioned array
DZ	EQU	14H		; Division by zero (/0)
ID	EQU	16H		; Illegal direct
TM	EQU	18H		; Type miss-match
OS	EQU	1AH		; Out of string space
LS	EQU	1CH		; String too long
ST	EQU	1EH		; String formula too complex
CN	EQU	20H		; Can't CONTinue
UF	EQU	22H		; UnDEFined FN function
MO	EQU	24H		; Missing operand
HX	EQU	26H		; HEX error
BN	EQU	28H		; BIN error
;
COLD:	JP	STARTB		; Jump for cold start
WARM:	JP	WARMST		; Jump for warm start
STARTB: JP	CSTART		; Jump to initialise
;
	DW	DEINT		; Get integer -32768 to 32767
	DW	ABPASS		; Return integer in AB
;
CSTART: LD	HL,WRKSPC	; Start of workspace RAM
	LD	SP,HL		; Set up a temporary stack
	JP	INITST		; Go to initialise
;
INIT:	LD	DE,INITAB	; Initialise workspace
	LD	B,INITBE-INITAB+3; Bytes to copy
	LD	HL,WRKSPC	; Into workspace RAM
COPY:	LD	A,(DE)		; Get source
	LD	(HL),A		; To destination
	INC	HL		; Next destination
	INC	DE		; Next source
	DEC	B		; Count bytes
	JP	NZ,COPY		; More to move
	LD	SP,HL		; Temporary stack
	CALL	CLREG		; Clear registers and stack
	CALL	PRCRLF		; Output CRLF
	LD	(BUFFER+72+1),A	; Mark end of buffer
	LD	(PROGST),A	; Initialise program area
MSIZE:	LD	HL,STLOOK	; Point to start of RAM
MLOOP:	INC	HL		; Next byte
	LD	A,H		; Above address FFFF ?
	OR	L
	JP	Z,SETTOP	; Yes - 64K RAM
	LD	A,(HL)		; Get contents
	LD	B,A		; Save it
	CPL			; Flip all bits
	LD	(HL),A		; Put it back
	CP	(HL)		; RAM there if same
	LD	(HL),B		; Restore old contents
	JP	Z,MLOOP		; If RAM - test next byte
;
SETTOP: DEC	HL		; Back one byte
	LD	DE,STLOOK-1	; See if enough RAM
	CALL	CPDEHL		; Compare DE with HL
	JP	C,NEMEM		; If not enough RAM
	LD	DE,0-50		; 50 Bytes string space
	LD	(LSTRAM),HL	; Save last available RAM
	ADD	HL,DE		; Allocate string space
	LD	(STRSPC),HL	; Save string space
	CALL	CLRPTR		; Clear program area
	LD	HL,(STRSPC)	; Get end of memory
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

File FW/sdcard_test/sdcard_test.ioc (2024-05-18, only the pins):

Mcu.UserName=STM32L476RGTx
PA0.Signal=S_TIM5_CH1
PA1.GPIO_Label=Z80_WAIT
PA1.Signal=GPIO_Input
PA10.GPIO_Label=Z80_A15
PA10.Signal=GPIO_Input
PA11.GPIO_Label=Z80_RD
PA11.Signal=GPIO_Input
PA12.GPIO_Label=Z80_WR
PA12.Signal=GPIO_Input
PA2.GPIO_Label=USART_TX
PA2.Signal=USART2_TX
PA3.GPIO_Label=USART_RX
PA3.Signal=USART2_RX
PA4.GPIO_Label=SPI1_SS
PA4.Signal=GPIO_Output
PA5.Signal=SPI1_SCK
PA6.GPIO_Label=BANK_SEL0
PA6.Signal=GPIO_Output
PA7.GPIO_Label=BANK_SEL1
PA7.Signal=GPIO_Output
PA8.GPIO_Label=Z80_A13
PA8.Signal=GPIO_Input
PA9.GPIO_Label=Z80_A14
PA9.Signal=GPIO_Input
PB0.GPIO_Label=Z80_NMI
PB0.Signal=GPIO_Output
PB1.GPIO_Label=Z80_MEMRQ
PB1.Signal=GPIO_Input
PB10.Signal=GPIO_Input
PB11.Signal=GPIO_Input
PB12.Signal=GPIO_Input
PB13.Signal=GPIO_Input
PB14.Signal=GPIO_Input
PB15.Signal=GPIO_Input
PB2.GPIO_Label=Z80_IOREQ
PB2.Signal=GPIO_Input
PB5.Signal=SPI1_MOSI
PB6.Signal=I2C1_SCL
PB7.Signal=I2C1_SDA
PB8.Signal=GPIO_Input
PB9.Signal=GPIO_Input
PC0.Signal=GPIO_Input
PC1.Signal=GPIO_Input
PC10.Signal=GPIO_Input
PC11.Signal=GPIO_Input
PC12.Signal=GPIO_Input
PC2.Signal=GPIO_Input
PC3.Signal=GPIO_Input
PC4.Signal=GPIO_Input
PC5.Signal=GPIO_Input
PC6.Signal=GPIO_Input
PC7.Signal=GPIO_Input
PC8.Signal=GPIO_Input
PC9.Signal=GPIO_Input
PD2.GPIO_Label=Z80_RESET
PD2.Signal=GPIO_Output

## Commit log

2024-03-24 Add Nucleo64_Z80 PCB revision 0.8
    [Nucleo64_Z80.kicad_pcb, Nucleo64_Z80.kicad_sch, optional.kicad_sch]
2024-03-25 Add FW/board_test
2024-03-25 fw: board_test: Flip SPI1_SS to blink DISK LED
    [main.c]
2024-03-25 fw: board_test: Use printf() instead of HAL_UART_Transmit()
2024-03-25 fw: board_test: Add empty board_test()
2024-03-25 fw: board_test: Enable pull-pull of WAIT, IORQ, MREQ, RD and WR
2024-03-25 fw: board_test: Write tiny program to the SRAM and run it (WIP)
2024-03-30 fw: board_test: Enable PORTC in CubeMX
2024-03-30 fw: board_test: Write tiny program to the SRAM and run it (fixed)
2024-03-31 fw: board_test: Use TIM5 to generate Z80 clock
2024-03-31 fw: board_test: Fix UART I/O address
2024-04-28 fw: board_test: Fix WAIT pin settings
    [main.c]
2024-04-28 fw: board_test: Add USART input
2024-04-28 fw: board_test: Use emubasic.inc
2024-04-28 fw: board_test: Use TIM1 and delay_us()
2024-04-28 fw: board_test: Fix GPIO macro definitions
    [main.c]
2024-05-11 Add Nucleo64_Z80 PCB revision 1.0
    [Nucleo64_Z80.kicad_pcb, Nucleo64_Z80.kicad_sch, optional.kicad_sch]
2024-05-11 fw: board_test: Fix pin assignment for PCB revision 1.0
    [main.c]
2024-05-12 fw: Add .gitignore for STM32 IDE files
2024-05-12 fw: Create new i2c_test from from board_test.ioc
2024-05-12 fw: i2c_test: Enable I2C1
2024-05-12 fw: i2c_test: Enable stdio and add delay_us()
2024-05-12 fw: i2c_test: Add I2C scanner
2024-05-12 fw: i2c_test: Add DS1307 RTC test
2024-05-18 fw: Create new sdcard_test from i2c_test.ioc
2024-05-18 fw: sdcard_test: Copy main.c from i2c_test
2024-05-18 fw: sdcard_test: Add FATFS sample code
    Tutorial: An SD card over SPI using STM32CubeIDE and FatFS
    https://01001000.xyz/2020-08-09-Tutorial-STM32CubeIDE-SD-card/
2024-05-18 fw: sdcard_test: Fix FATFS sample code
    [main.c]
2024-05-18 Add Nucleo64_Z80 PCB revision 1.1
    [Nucleo64_Z80.kicad_pcb, Nucleo64_Z80.kicad_sch, optional.kicad_sch]
2024-05-18 Add Nucleo64_Z80 PCB revision 1.2
    [Nucleo64_Z80.kicad_pcb, Nucleo64_Z80.kicad_sch, optional.kicad_sch]
2025-12-29 fw: h503_usb_host_test: Add ThreadX and USBX
2025-12-29 fw: h503_usb_host_test: Fix USBX configuration parameters
    [h503_usb_host_test.ioc]
